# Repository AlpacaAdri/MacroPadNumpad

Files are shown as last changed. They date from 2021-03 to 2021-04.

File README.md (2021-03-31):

# MacroPadNumpad
A custom Arduino based numpad made in Kicad.

This repo contains both the KICAD project files for the macropad PCB as well as the Arduino code needed to run it.
This project also uses the MX_Alpas_Hybrid library from https://github.com/ai03-2725/MX_Alps_Hybrid

this is very much a work in progress

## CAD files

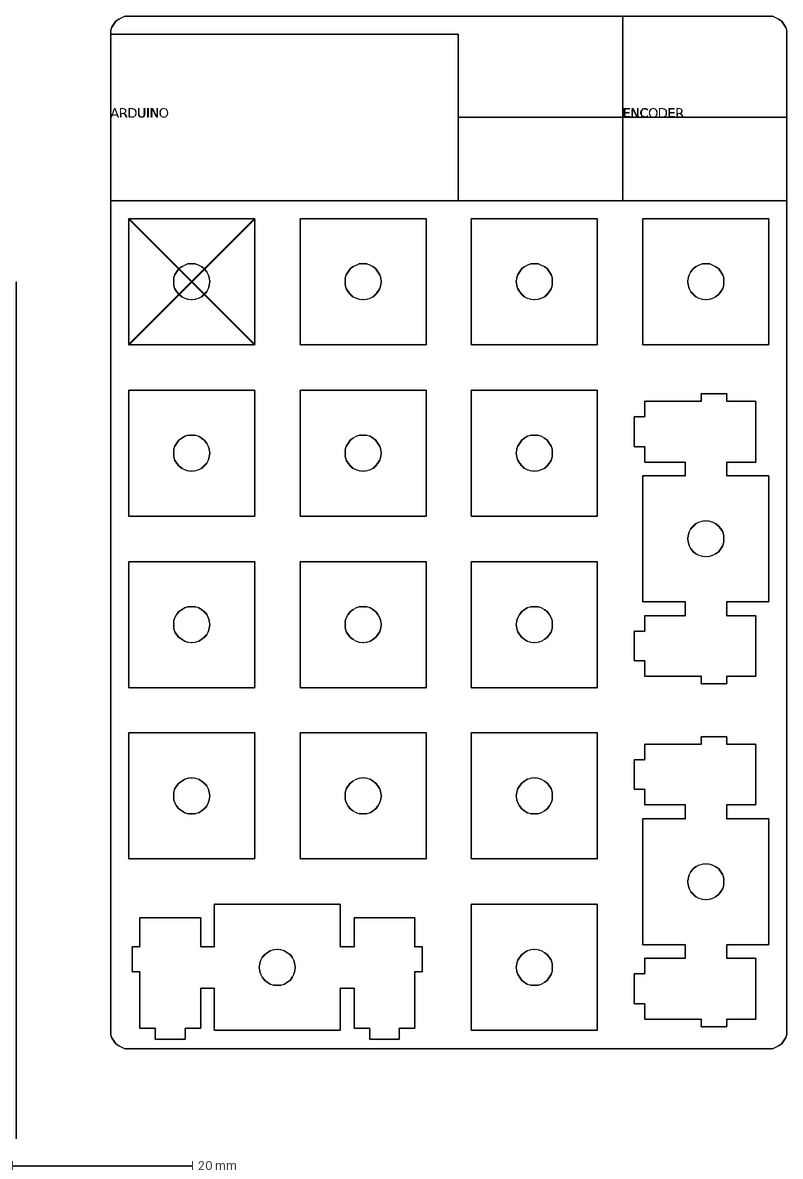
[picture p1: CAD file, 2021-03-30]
PCB/#pcbTotal.dxf
ARDUINO
ENCODER

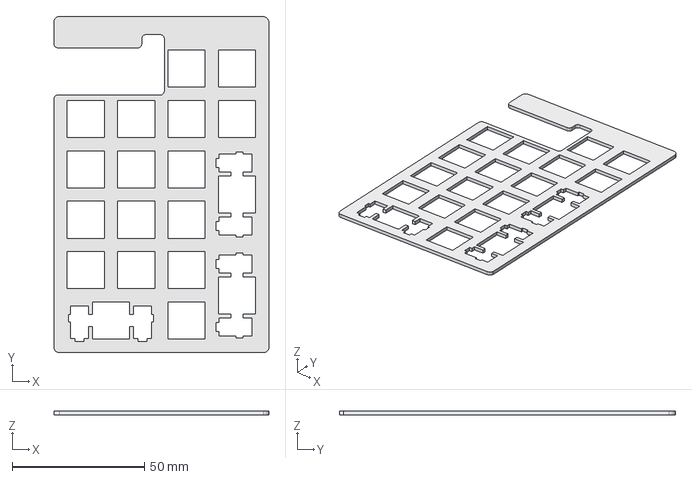
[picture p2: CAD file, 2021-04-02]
numPadPlate.FCStd
81.2 x 126.9 x 1.52 mm

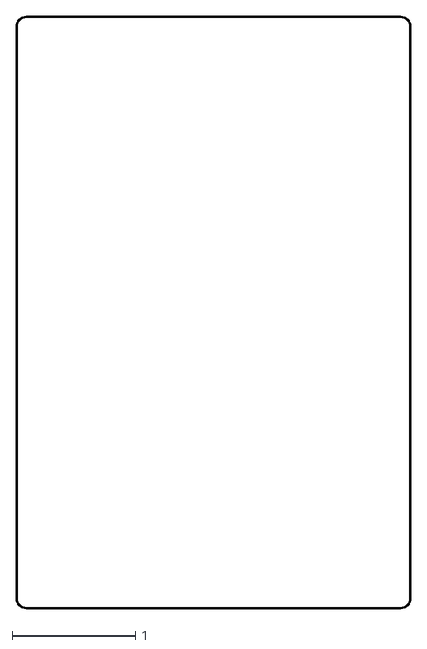
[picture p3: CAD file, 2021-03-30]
PCB/Dxfs/KeypadMacropad1-Edge_Cuts.dxf
3.20 x 4.81

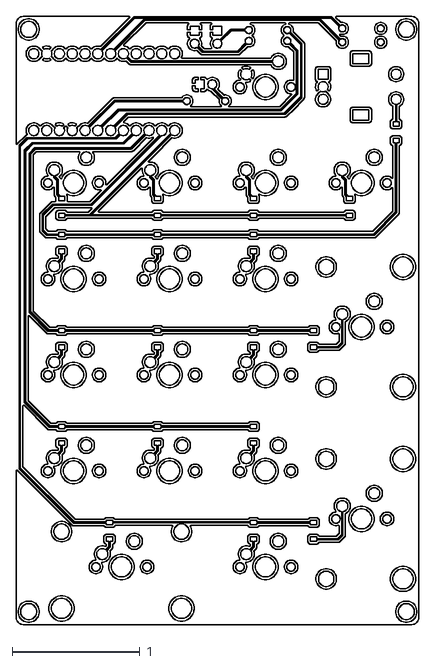
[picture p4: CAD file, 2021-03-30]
PCB/Dxfs/KeypadMacropad1-B_Cu.dxf
3.15 x 4.75

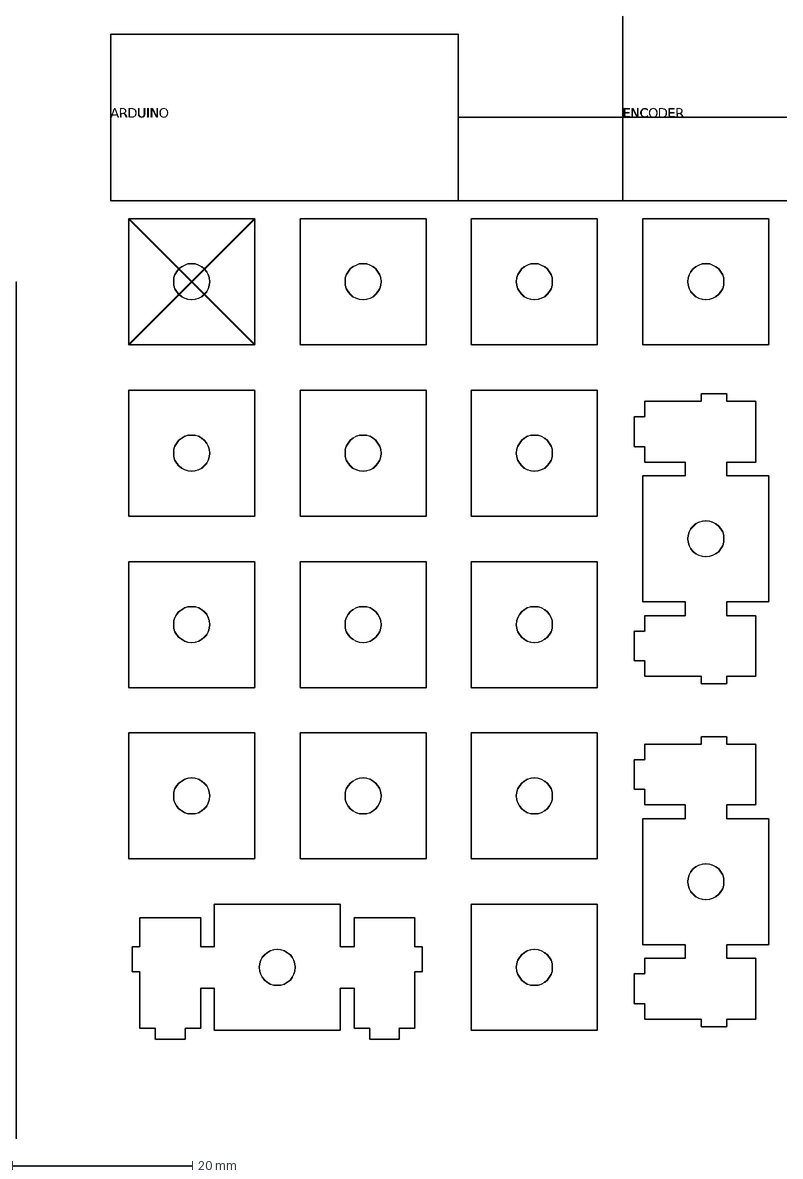
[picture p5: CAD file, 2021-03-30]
PCB/keysRef.dxf
ARDUINO
ENCODER

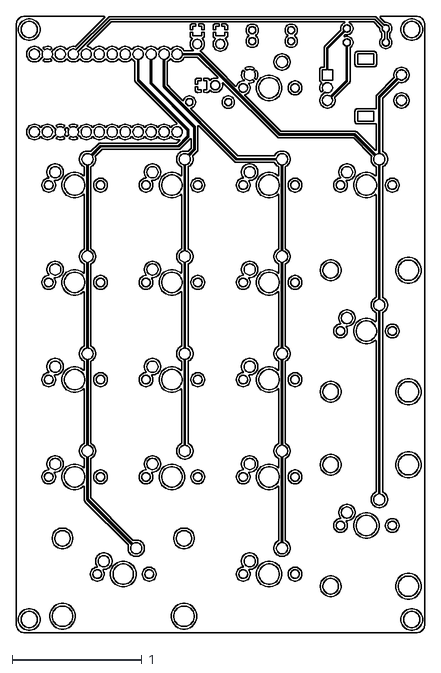
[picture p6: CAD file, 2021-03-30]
PCB/Dxfs/KeypadMacropad1-F_Cu.dxf
3.15 x 4.75

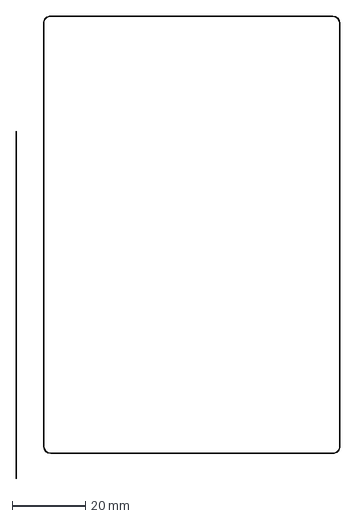
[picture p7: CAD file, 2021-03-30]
PCB/Dxfs/border.dxf
88.7 x 126.8 mm

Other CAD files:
PCB/Dxfs/KeypadMacropad1-B_Mask.dxf
PCB/Dxfs/KeypadMacropad1-B_Paste.dxf
PCB/Dxfs/KeypadMacropad1-B_SilkS.dxf
PCB/Dxfs/KeypadMacropad1-F_Mask.dxf
PCB/Dxfs/KeypadMacropad1-F_Paste.dxf
PCB/Dxfs/KeypadMacropad1-F_SilkS.dxf
PCB/pcbTotal.dxf
numPadPlate.obj

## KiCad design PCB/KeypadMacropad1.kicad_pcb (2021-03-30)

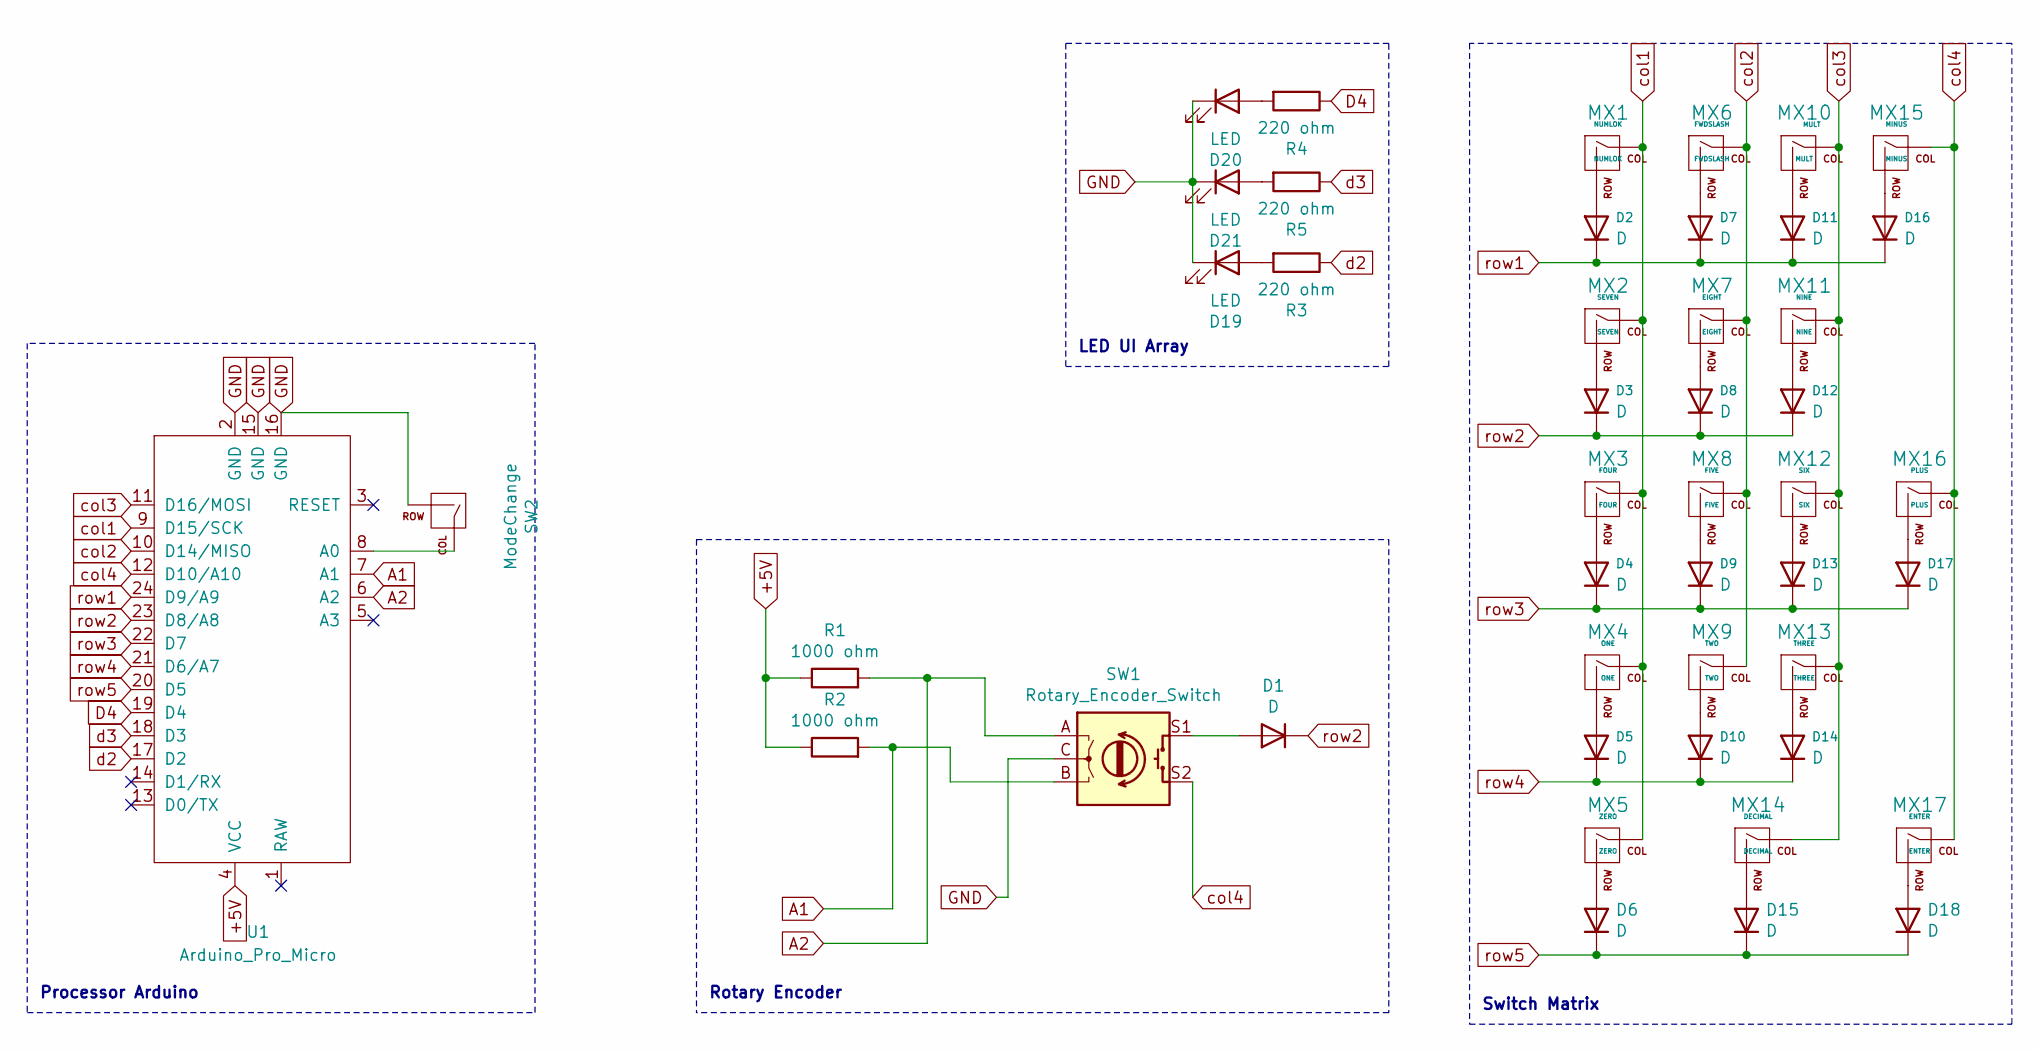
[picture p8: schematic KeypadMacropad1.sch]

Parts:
D1, D2, D3, D4, D5, D6, D7, D8, D9, D10, D11, D12, D13, D14, D15, D16, D17, D18: D; D_SOD-123
D19, D20, D21: LED; LED_D3.0mm
MX1: NUMLOK; SW_Cherry_MX_1.00u_PCB
MX2: SEVEN; SW_Cherry_MX_1.00u_PCB
MX3: FOUR; SW_Cherry_MX_1.00u_PCB
MX4: ONE; SW_Cherry_MX_1.00u_PCB
MX5: ZERO; SW_Cherry_MX_2.00u_PCB
MX6: FWDSLASH; SW_Cherry_MX_1.00u_PCB
MX7: EIGHT; SW_Cherry_MX_1.00u_PCB
MX8: FIVE; SW_Cherry_MX_1.00u_PCB
MX9: TWO; SW_Cherry_MX_1.00u_PCB
MX10: MULT; SW_Cherry_MX_1.00u_PCB
MX11: NINE; SW_Cherry_MX_1.00u_PCB
MX12: SIX; SW_Cherry_MX_1.00u_PCB
MX13: THREE; SW_Cherry_MX_1.00u_PCB
MX14: DECIMAL; SW_Cherry_MX_1.00u_PCB
MX15: MINUS; SW_Cherry_MX_1.00u_PCB
MX16: PLUS; SW_Cherry_MX_2.00u_Vertical_PCB
MX17: ENTER; SW_Cherry_MX_2.00u_Vertical_PCB
R1, R2: 1000 ohm; R_Axial_DIN0204_L3.6mm_D1.6mm_P7.62mm_Horizontal
R3, R4, R5: 220 ohm; R_Axial_DIN0204_L3.6mm_D1.6mm_P7.62mm_Horizontal
SW1: Rotary_Encoder_Switch; RotaryEncoder_Alps_EC11E-Switch_Vertical_H20mm
SW2: ModeChange; SW_Cherry_MX_1.00u_PCB
U1: Arduino_Pro_Micro

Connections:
+5V: R1.1, R2.1, U1.4 (VCC)
A1: R2.2, SW1.B, U1.7 (A1)
A2: R1.2, SW1.A, U1.6 (A2)
D4: R4.1, U1.19 (D4)
GND: D19.1 (K), D20.1 (K), D21.1 (K), SW1.C, SW2.2 (ROW), U1.2 (GND), U1.15 (GND), U1.16 (GND)
unnamed: D1.2 (A), SW1.S1
unnamed: D2.2 (A), MX1.2 (ROW)
unnamed: D3.2 (A), MX2.2 (ROW)
unnamed: D4.2 (A), MX3.2 (ROW)
unnamed: D5.2 (A), MX4.2 (ROW)
unnamed: D6.2 (A), MX5.2 (ROW)
unnamed: D7.2 (A), MX6.2 (ROW)
unnamed: D8.2 (A), MX7.2 (ROW)
unnamed: D9.2 (A), MX8.2 (ROW)
unnamed: D10.2 (A), MX9.2 (ROW)
unnamed: D11.2 (A), MX10.2 (ROW)
unnamed: D12.2 (A), MX11.2 (ROW)
unnamed: D13.2 (A), MX12.2 (ROW)
unnamed: D14.2 (A), MX13.2 (ROW)
unnamed: D15.2 (A), MX14.2 (ROW)
unnamed: D16.2 (A), MX15.2 (ROW)
unnamed: D17.2 (A), MX16.2 (ROW)
unnamed: D18.2 (A), MX17.2 (ROW)
unnamed: D19.2 (A), R3.2
unnamed: D20.2 (A), R4.2
unnamed: D21.2 (A), R5.2
unnamed: SW2.1 (COL), U1.8 (A0)
col1: MX1.1 (COL), MX2.1 (COL), MX3.1 (COL), MX4.1 (COL), MX5.1 (COL), U1.9 (D15/SCK)
col2: MX6.1 (COL), MX7.1 (COL), MX8.1 (COL), MX9.1 (COL), U1.10 (D14/MISO)
col3: MX10.1 (COL), MX11.1 (COL), MX12.1 (COL), MX13.1 (COL), MX14.1 (COL), U1.11 (D16/MOSI)
col4: MX15.1 (COL), MX16.1 (COL), MX17.1 (COL), SW1.S2, U1.12 (D10/A10)
d2: R3.1, U1.17 (D2)
d3: R5.1, U1.18 (D3)
row1: D2.1 (K), D7.1 (K), D11.1 (K), D16.1 (K), U1.24 (D9/A9)
row2: D1.1 (K), D3.1 (K), D8.1 (K), D12.1 (K), U1.23 (D8/A8)
row3: D4.1 (K), D9.1 (K), D13.1 (K), D17.1 (K), U1.22 (D7)
row4: D5.1 (K), D10.1 (K), D14.1 (K), U1.21 (D6/A7)
row5: D6.1 (K), D15.1 (K), D18.1 (K), U1.20 (D5)

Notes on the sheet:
Rotary Encoder
Switch Matrix
LED UI Array
Processor Arduino

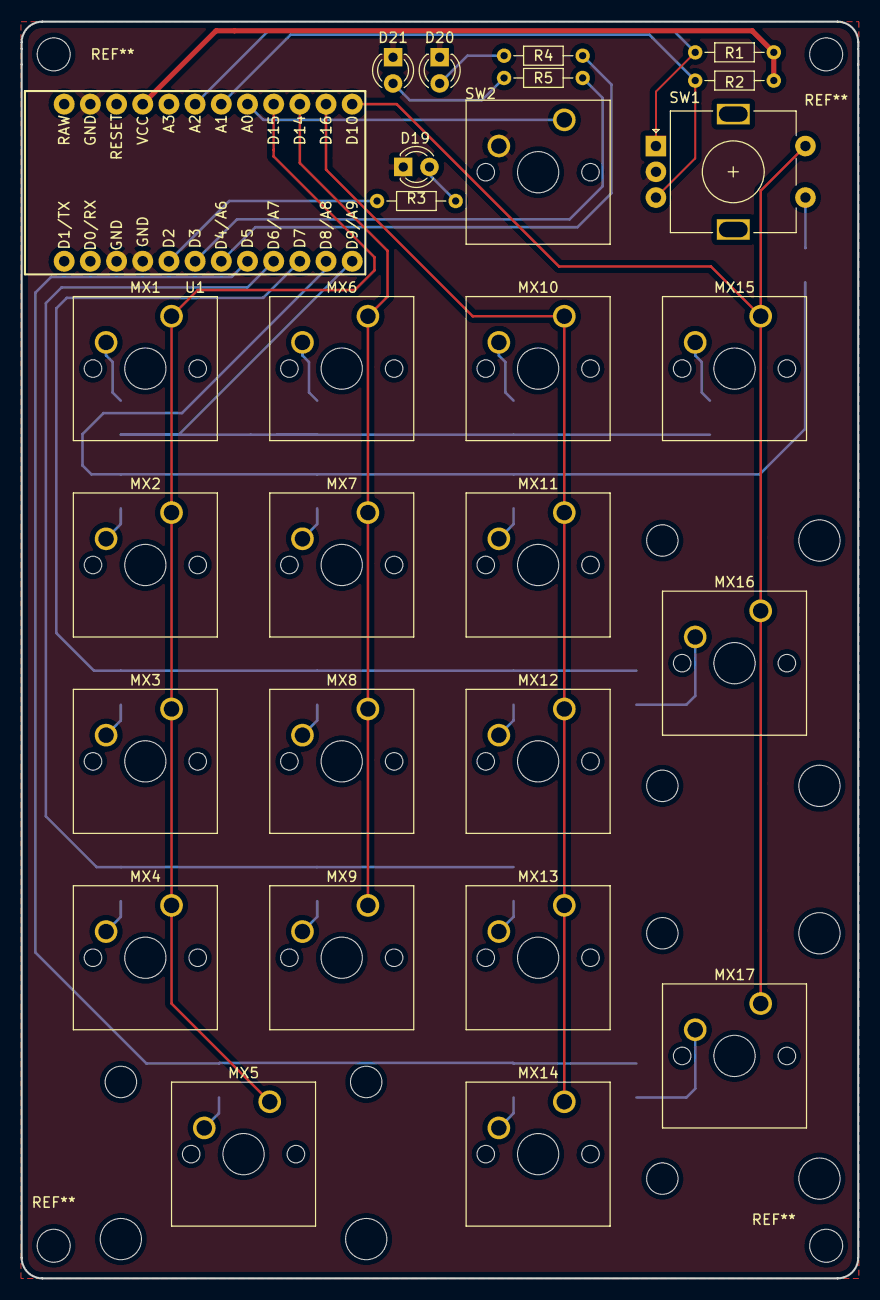
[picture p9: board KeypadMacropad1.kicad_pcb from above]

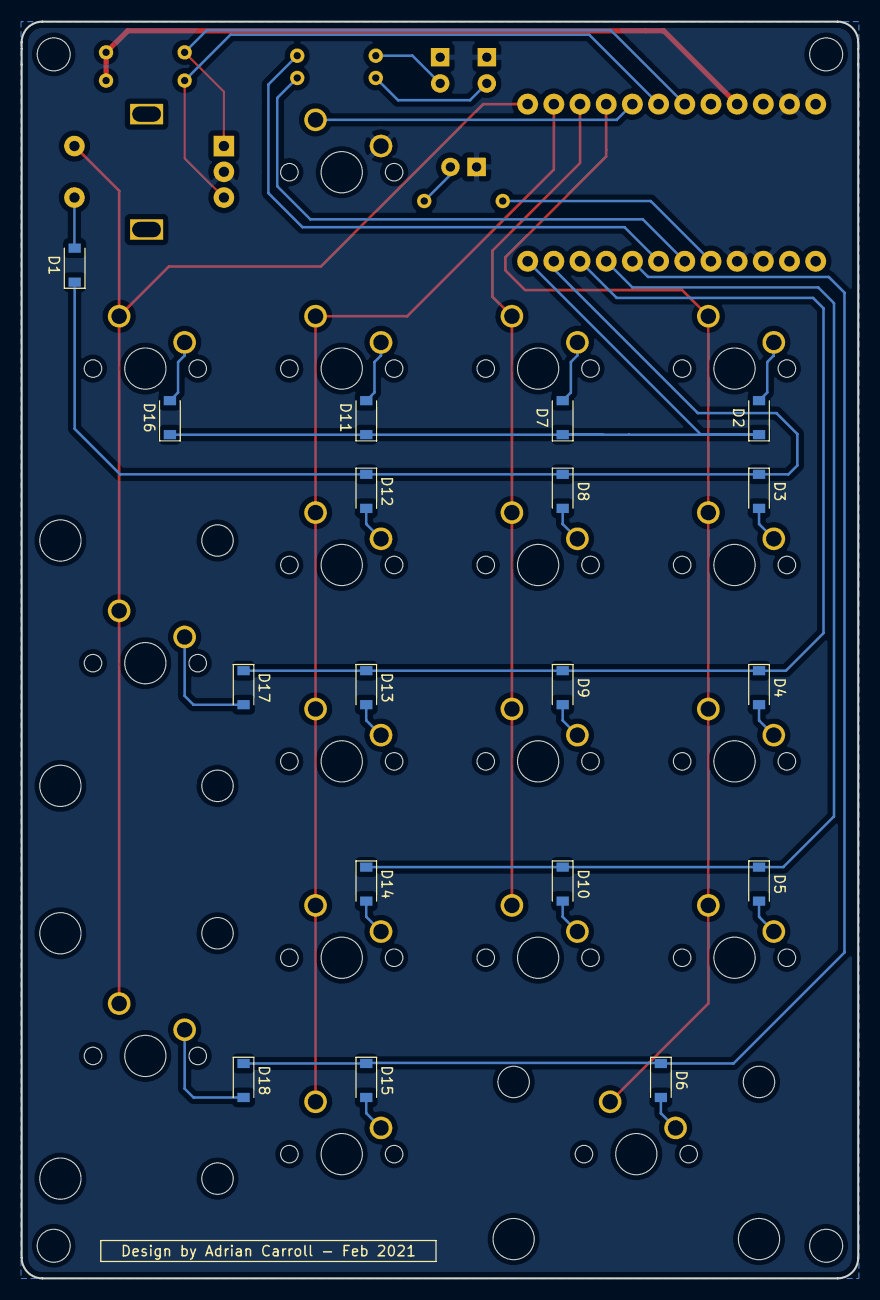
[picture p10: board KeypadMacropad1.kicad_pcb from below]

Board: 2 copper layers, 81.2 x 121.9 mm, 46 parts (18 on the bottom side), 38 nets.

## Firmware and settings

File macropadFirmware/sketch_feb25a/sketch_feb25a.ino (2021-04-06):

#include <Keyboard.h>
#include <Encoder.h>


/*
   TODO

   make encoder checking function:

   make matrix scanning function - output ID of pressed switch:
   V
   pass output of scanning function to keybinding function - convert button press to key strokes: DONE
   V
   output keybinding function to computer: DONE
*/

byte rows[] = {15, 14, 16, 10}; //pins for columns
byte cols[] = {9, 8, 7, 6, 5}; //pins for rows

const int colCount = sizeof(cols) / sizeof(cols[0]);
const int rowCount = sizeof(rows) / sizeof(rows[0]);

//overall control vars
byte mode = 0;//what mode am I in?
bool numlok = true; //is the numlock button on?
bool * pointNumLok = &numlok;

int spamSpeed = 15;
int longPressDelay = 350;


//spamSpeed arr helpers
bool keyDown[colCount][rowCount]; //which keys are pressed down


//key nums
byte layout[5][4] = {               //layout grid for characters
  {0, 1, 2, 3},
  {4, 5, 6, 7},
  {8, 9, 10, 11},
  {12, 13, 14, -1}, //-1s are for indexes where nothing is wired to the arduino
  {16, -1, 18, 19}
};

//encoder setup


void setup() {
  // put your setup code here, to run once:
  Serial.begin(1500);

  //testing, delete later
  pinMode(A3, INPUT);//disable keyboard pin

  pinMode(2, OUTPUT);//numlok LED output
  pinMode(A0, INPUT_PULLUP);//numlok key input
  pinMode(3, OUTPUT);//left mode disp LED
  pinMode(4, OUTPUT);//right mode disp LED
  pinMode(A1, INPUT);//encoder pin
  pinMode(A2, INPUT);//Encoder pin 2

  for (int i = 0; i < rowCount; i++) {
    Serial.print(rows[i]); Serial.println(" as input");
    pinMode(rows[i], INPUT_PULLUP);
  }

  for (int i = 0; i < colCount; i++) {
    Serial.print(cols[i]); Serial.println(" as output");
    pinMode(cols[i], OUTPUT);
  }


  Keyboard.begin();
}


void keyPressed(int row, int col) {
  if (keyDown[row][col] == 0) {     //if the function is called for the first time for this key
    switch (mode) {
      case 0:
        mode0(layout[row][col], numlok, pointNumLok);
        break;

      case 1:
        mode1(layout[row][col], numlok, pointNumLok);
        break;

      case 2:
        mode2(layout[row][col], numlok, pointNumLok);
        break;

      case 3:
        mode3(layout[row][col], numlok, pointNumLok);
        break;
    }
  }
  keyDown[row][col] = true;
 
    

  
}

void resetKey(int row, int col) { //resetting the variables after key is released
  keyDown[row][col] = false;
  //keyLong[row][col] = false;
  switch (mode) {
    case 0:
      releaseMode0(layout[row][col], numlok);
      break;

    case 1:
      releaseMode1(layout[row][col], numlok);
      break;

    case 2:
      releaseMode2(layout[row][col], numlok);
      break;

    case 3:
      releaseMode3(layout[row][col], numlok);
      break;
  }
}

void LEDDisplay(byte mode, bool numlok) {
  //display mode
  if ((mode & 1) > 0) {
    digitalWrite(4, HIGH); //get first bit of mode > if the first bit is > 0, then light up right LED
  } else {
    digitalWrite(4, LOW);
  }
  if ((mode & 2) > 0) {
    digitalWrite(3, HIGH); //get second bit of mode > if the second bit is > 0, then light up left LED
  } else {
    digitalWrite(3, LOW);
  }
  if (numlok) {
    digitalWrite(2, HIGH); //display numlok LED
  } else {
    digitalWrite(2, LOW);
  }
}


void loop() {
  // put your main code here, to run repeatedly:

  //scan matrix
  for (int c = 0; c < colCount; c++) {
    digitalWrite(cols[c], LOW); //set a column low
    delayMicroseconds(5); //setttle down little electrons

    for (int r = 0; r < rowCount; r++) { //check rows
      if (digitalRead(rows[r]) == LOW)
      {
        keyPressed(c, r);           //calling keyPressed function if one of the inputs reads low
      }
      else if (keyDown[c][r] != 0)  //resetting the key if it is not pressed any more
      {
        resetKey(c, r);
      }

    }
    digitalWrite(cols[c], HIGH);//reset col
    delayMicroseconds(500);
  }

  //check encoder
 

  //check if modeSwitch is pressed
  while (digitalRead(A0) == LOW) {
    mode++;
    if (mode > 3) {
      mode = 0;
    }
    delay(500);
    LEDDisplay(mode, numlok);//show mode going up in binary on LEDs
  }

  //display to LEDs
  LEDDisplay(mode, numlok);
  //Emergency Testing disable
  if (digitalRead(A3) == HIGH) {
    Keyboard.end();
  }


}

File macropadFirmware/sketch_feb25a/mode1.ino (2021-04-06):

/*  default - without bindings
   layout:

   (unused) (1) (2) (3)
   (4) (5) (6) (7)
   (8) (9) (10) (11)
   (12) (13) (14) (-1)
   (16) (-1) (18) (19)

*/
//gaming mode

void mode1(byte keyNum, bool numlok, bool * pointNumLok) {

  if (numlok) {
    switch (keyNum) {
      case 0:
        *pointNumLok = !numlok; //if numlok is pressed, flip numlok.
        break;
      case 1:// '/' key
        //open terminal
        Keyboard.press(0x83);
        Keyboard.press(0xB0);
        Keyboard.releaseAll();
        break;
      case 2:// '*' key

        break;
      case 3:// '-' key

        break;
      case 4:// '7' key
        //switch to desktop 7
        Keyboard.press(0x83);
        Keyboard.press('7');
        Keyboard.releaseAll();
        delay(50);
        break;
      case 5:// '8' key
        //switch to desktop 8
        Keyboard.press(0x83);
        Keyboard.press('8');
        Keyboard.releaseAll();
        break;
      case 6:// '9' key
        //switch to desktop 9
        Keyboard.press(0x83);
        Keyboard.press('9');
        Keyboard.releaseAll();
        delay(50);
        break;
      case 7:// 'ENCODER' key

        break;
      case 8:// '4' key
        //switch to desktop 4
        Keyboard.press(0x83);
        Keyboard.press('4');
        Keyboard.releaseAll();
        delay(50);
        break;
      case 9:// '5' key
        //switch to desktop 5
        Keyboard.press(0x83);
        Keyboard.press('5');
        Keyboard.releaseAll();
        delay(50);
        break;
      case 10:// '6' key
        //switch to desktop 6
        Keyboard.press(0x83);
        Keyboard.press('6');
        Keyboard.releaseAll();
        delay(50);
        break;
      case 11://'+' key
        //open drun
        Keyboard.press(0x83);
        Keyboard.press(0x20);
        Keyboard.releaseAll();

        break;
      case 12:// '1' key
        //switch to desktop 1
        Keyboard.press(0x83);
        Keyboard.press('1');
        Keyboard.releaseAll();
        break;
      case 13://'2' key
        //switch to desktop 2
        Keyboard.press(0x83);
        Keyboard.press('2');
        Keyboard.releaseAll();
        break;
      case 14:// '3' key
        //switch to desktop 3
        Keyboard.press(0x83);
        Keyboard.press('3');
        Keyboard.releaseAll(); 
        delay(50);
        break;
      case 16:// '0' key
        //open browser window
        Keyboard.press(0x83);
        Keyboard.press(0x81);
        Keyboard.press(0xB0);
        Keyboard.releaseAll();
        delay(50);
        break;
      case 18://'.' key
        //close current window
        Keyboard.press(0x83);
        Keyboard.press(0x81);
        Keyboard.press('q');
        Keyboard.releaseAll();
        delay(50);
        break;
      case 19://'ENTER' key
        Keyboard.press(176);
        break;
    }
  } else {
    switch (keyNum) {
      case 0:
        *pointNumLok = !numlok; //if numlok is pressed, flip numlok.
        break;
      case 1:// '/' key

        break;
      case 2:// '*' key

        break;
      case 3:// '-' key

        break;
      case 4:// '7' key
        Keyboard.press(0x83);
        Keyboard.press(0x20);
        Keyboard.releaseAll();
        delay(1000);
        Keyboard.print("arduino");
        delay(500);
        Keyboard.write(0xB0);
        break;
      case 5:// '8' key

        break;
      case 6:// '9' key

        break;
      case 7:// 'ENCODER' key

        break;
      case 8:// '4' key
        Keyboard.press(0x83);
        Keyboard.press(0x20);
        Keyboard.releaseAll();
        delay(1000);
        Keyboard.print("thunderbird");
        delay(500);//add delay so user can see what they have launched
        Keyboard.write(0xB0);
        break;
      case 9:// '5' key
        Keyboard.press(0x83);
        Keyboard.press(0x20);
        Keyboard.releaseAll();
        delay(1000);
        Keyboard.print("htop");
        delay(500);
        Keyboard.write(0xB0);
        break;
      case 10:// '6' key
        Keyboard.press(0x83);
        Keyboard.press(0x20);
        Keyboard.releaseAll();
        delay(1000);
        Keyboard.print("PrusaSlicer");
        delay(500);
        Keyboard.write(0xB0);
        break;
      case 11://'+' key
        //open drun
        Keyboard.press(0x83);
        Keyboard.press(0x20);
        Keyboard.releaseAll();
        break;
      case 12:// '1' key
        Keyboard.press(0x83);
        Keyboard.press(0x20);
        Keyboard.releaseAll();
        delay(1000);
        Keyboard.print("nautilus");
        delay(500);//add delay so user can see what they have launched
        Keyboard.write(0xB0);
        break;
      case 13://'2' key
        Keyboard.press(0x83);
        Keyboard.press(0x20);
        Keyboard.releaseAll();
        delay(1000);
        Keyboard.print("Discord");
        delay(500);
        Keyboard.write(0xB0);
        break;
      case 14:// '3' key
        Keyboard.press(0x83);
        Keyboard.press(0x20);
        Keyboard.releaseAll();
        delay(1000);
        Keyboard.print("System monitor");
        delay(500);
        Keyboard.write(0xB0);
        break;
      case 16:// '0' key

        break;
      case 18://'.' key
        //close current window
        Keyboard.press(0x83);
        Keyboard.press(0x81);
        Keyboard.press('q');
        Keyboard.releaseAll();
        break;
      case 19://'ENTER' key
        Keyboard.write(176);
        break;
    }
  }
}
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

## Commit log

2021-03-30 rearranged files
    [KeypadMacropad1-B_Cu.dxf, KeypadMacropad1-B_Mask.dxf, KeypadMacropad1-B_Paste.dxf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]
2021-03-30 removed gerbers
2021-03-30 moved arduino footprint to internal library
    [KeypadMacropad1.kicad_pcb]
2021-03-30 new file: PCB/#pcbTotal.dxf new file: PCB/Dxfs/KeypadMacropad1-B_Cu.dxf new file: PCB/Dxfs/KeypadMacropad1-B_Mask.dxf new file: PCB/Dxfs/KeypadMacropad1-B_Paste.dxf new file: PCB/Dxfs/KeypadMacropad1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
    [#pcbTotal.dxf, KeypadMacropad1-B_Cu.dxf, KeypadMacropad1-B_Mask.dxf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]
2021-03-30 deleted: KeypadMacropad1/#pcbTotal.dxf deleted: KeypadMacropad1/Dxfs/KeypadMacropad1-B_Cu.dxf deleted: KeypadMacropad1/Dxfs/KeypadMacropad1-B_Mask.dxf deleted: KeypadMacropad1/Dxfs/KeypadMacropad1-B_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
    [#pcbTotal.dxf, KeypadMacropad1-B_Cu.dxf, KeypadMacropad1-B_Mask.dxf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]
2021-04-02 added FreeCad model for front plate
    [numPadPlate.FCStd]
2021-04-02 added 3d model of plate
    [numPadPlate.FCStd, numPadPlate.obj]
2021-04-02 modified plate
    [numPadPlate.FCStd]
2021-04-02 deleted: numPadPlate.obj
    [numPadPlate.obj]
2021-04-02 remade numPadPlate
    [numPadPlate.FCStd]
2021-04-04 reorganized Arduino code
2021-04-04 fixed issue with rows[] and cols[] not matching with hardware
    [sketch_feb25a.ino]
2021-04-04 fixed issue #5 with long pressed keys
    [sketch_feb25a.ino]
2021-04-05 made restructure branch
    [numPadPlate.obj]
